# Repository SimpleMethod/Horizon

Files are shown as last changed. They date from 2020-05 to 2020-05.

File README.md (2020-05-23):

# 📡Horizon - Meteorological System based on Internet of things

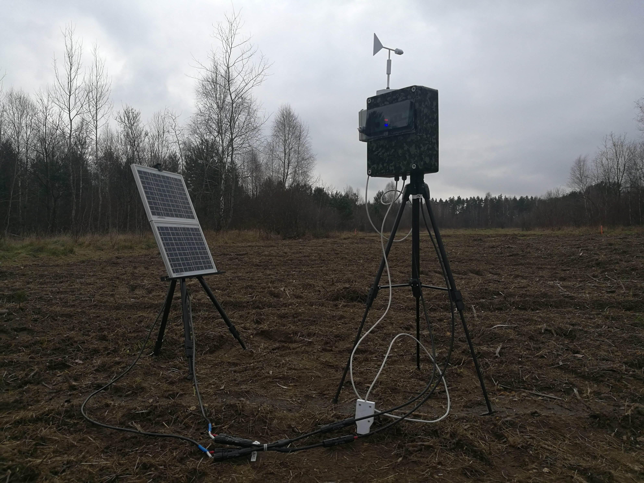
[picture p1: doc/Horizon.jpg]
Horizon in action


# 🥰 Best engineering thesis at university of technology in faculty of Electrical Engineering, Automatics and Computer Science 🥰
https://weaii.tu.kielce.pl/2020/05/15/wyniki-konkursu-prac-dyplomowych-ieee-2020/

# 🧗‍♂️Main milestones

1. Development of a device for measuring atmospheric conditions.
2. Development of a device for receiving telemetry and sending it to IoT server. 
3. Development of an IoT server able to collect data and analyse.
4. Development of an instrument for wind direction mapping.  

# 🚀 Features
 1. Getting meteorological data such as:
 - Air temperature,
 - Atmospheric pressure,
- Air humidity,
- Soil moisture,
- Wind direction,
- Dust value 2.5 PM and 10 PM.
2.  Communication between weather stations and base stations using IEEE 802.11 standard.
3.  Sending received data to IoT server via GSM communication from base stations.
4.  Ability to view data via a graphical interface from any device.
5. IoT server aggregating and analyzing data. 

# 🗺️ Technologies used in project 
1. Weather station:
- Based on two microcontainers:  STM32 and ESP32 programmed in C++. Development of necessary libraries based on technical documentation,
- Used LTC415 as voltage monitor,
- Photovoltaic panels,
- Voltage regulator,
- Gel rechargeable battery.
2. Receiving station:
- Used ESP32  programmed in C++. Development of necessary libraries based on technical documentation,
- Used SIM700e as GSM modem.
3. IoT server:
- Used microservice architecture,
- Based completely on AWS services (AWS Lambda, Amazon DynamoDB, API gateway, IAM), Lambda programmed in Node.JS,
- Graphical interface based on AngularJS running in one page. 

# 🧪 Visualization of weather station PCB 
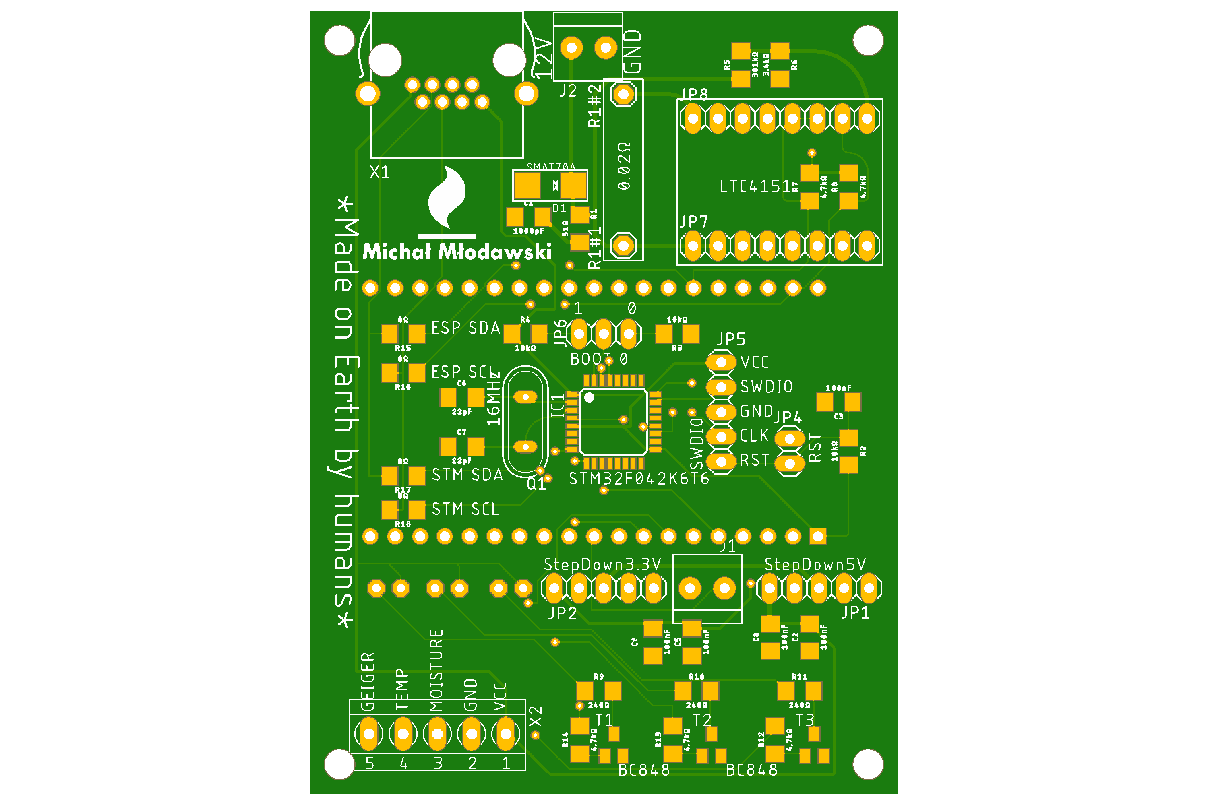
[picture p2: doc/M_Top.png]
Visualization of weather station PCB

## 🧶  Weather station communication diagram
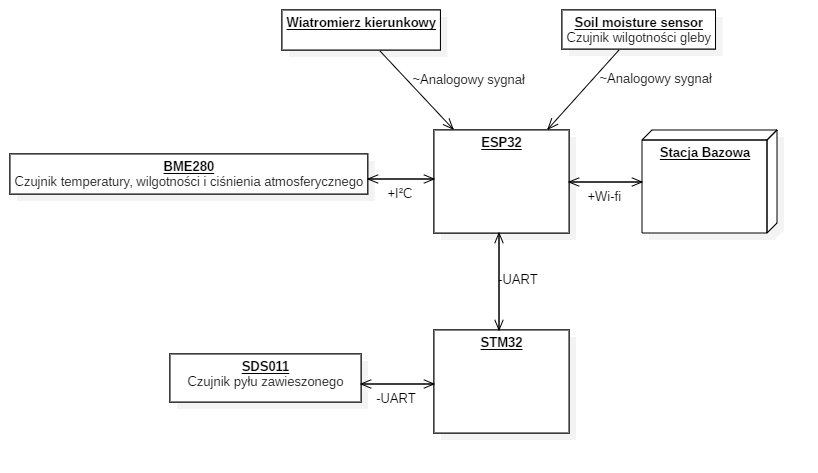
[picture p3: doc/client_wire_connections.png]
Weather station communication diagram


# 📈  Communication diagram
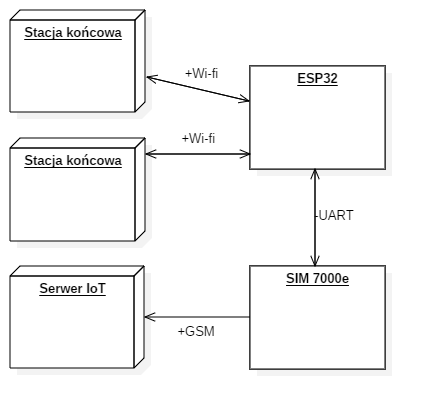
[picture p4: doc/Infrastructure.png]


# 🧊 Database schema
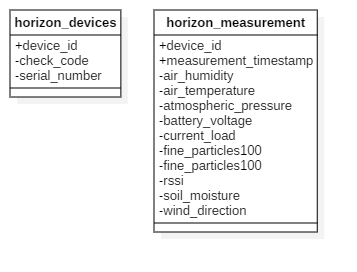
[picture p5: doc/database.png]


# 📙 Soil moisture sensor case
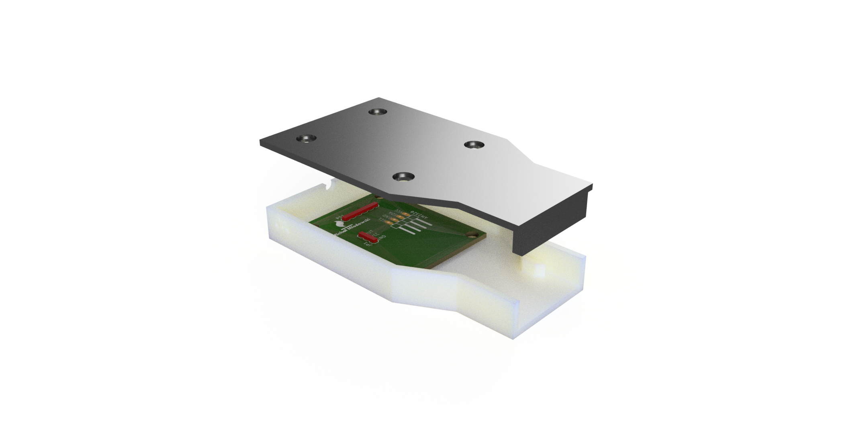
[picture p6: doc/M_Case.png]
Soil moisture sensor case


# 🧭 Wind vane 
Working on the measurement of change of resistance.
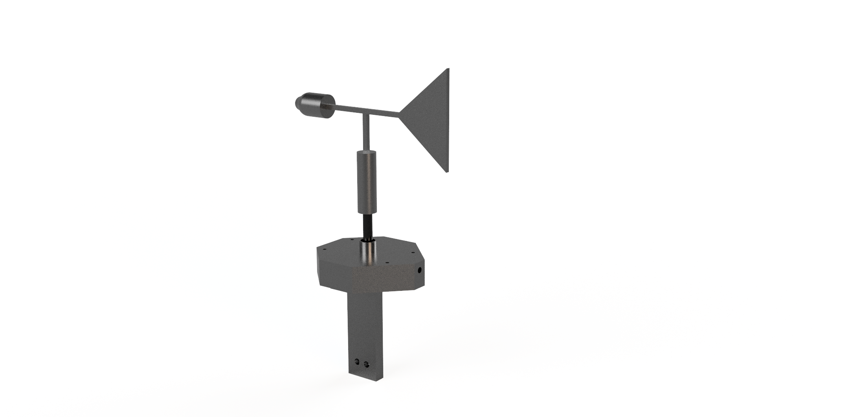
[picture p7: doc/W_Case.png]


## Visualization of PCB
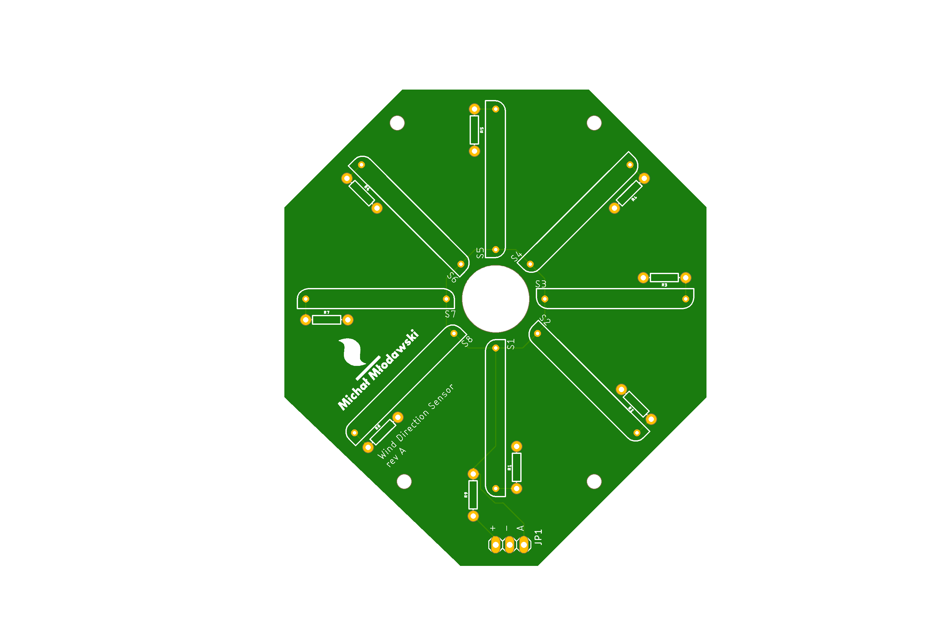
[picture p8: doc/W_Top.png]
Wind vane pcb


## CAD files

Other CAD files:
Client station/Wiring diagram of entire system/Wiring diagram AutoCAD Electrical/Stacja końcowa.dwg

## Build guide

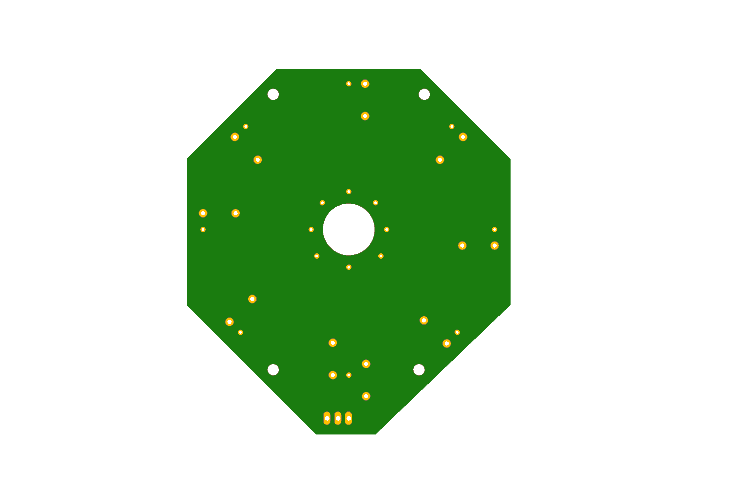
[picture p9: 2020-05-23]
Client station/Weather vane/PCB files/Wiring diagram PNG files/Graphical visualisation of PCB/Botton side.png

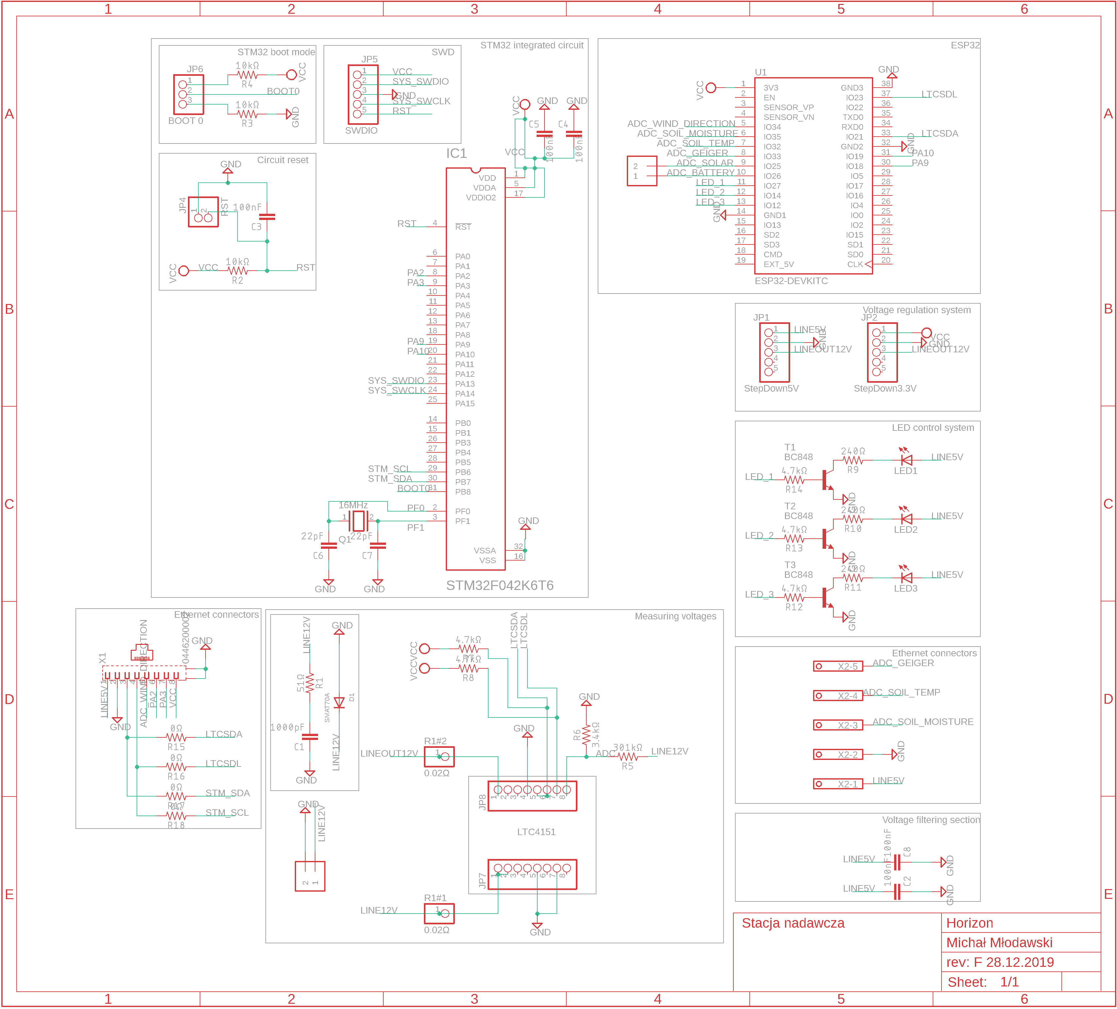
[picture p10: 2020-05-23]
Client station/Mainboard pcb files/Wiring diagram PNG files/Wiring diagram.png

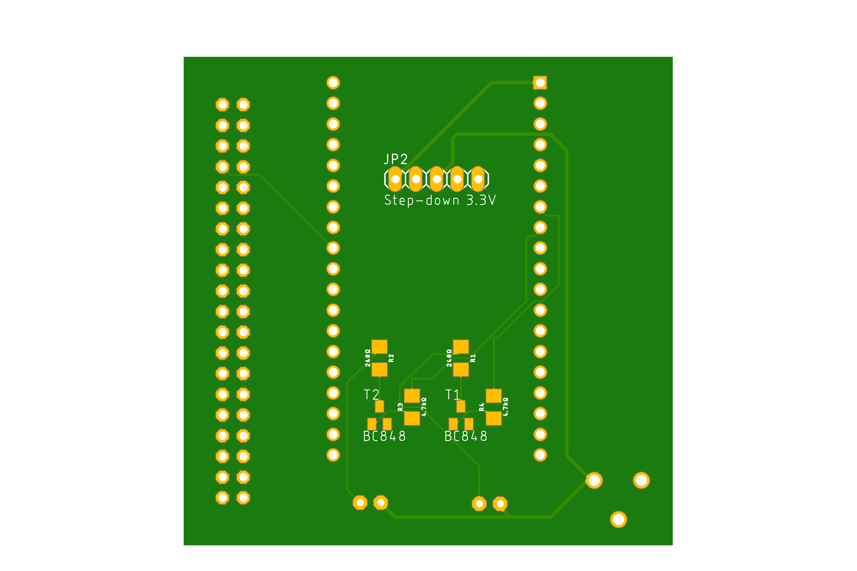
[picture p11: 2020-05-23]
Base station/Mainboard pcb files/Wiring diagram PNG files/Graphical visualisation of PCB/Botton side.png

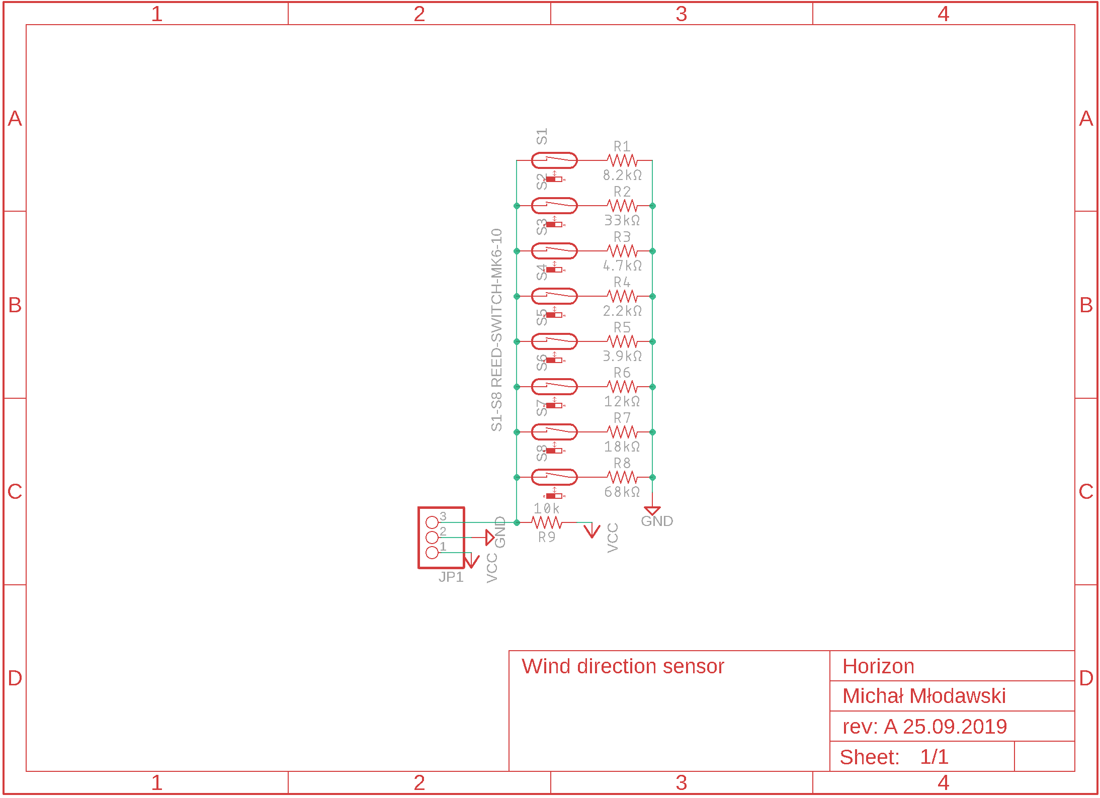
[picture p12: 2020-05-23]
Client station/Weather vane/PCB files/Wiring diagram PNG files/Wiring diagram/Wind direction sensor.png

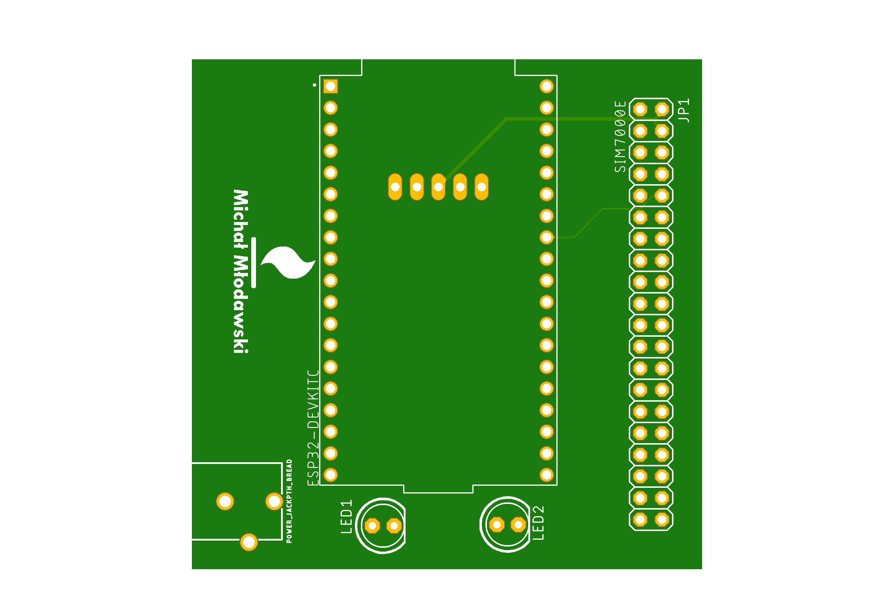
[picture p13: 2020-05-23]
Base station/Mainboard pcb files/Wiring diagram PNG files/Graphical visualisation of PCB/TOP SIDE.png

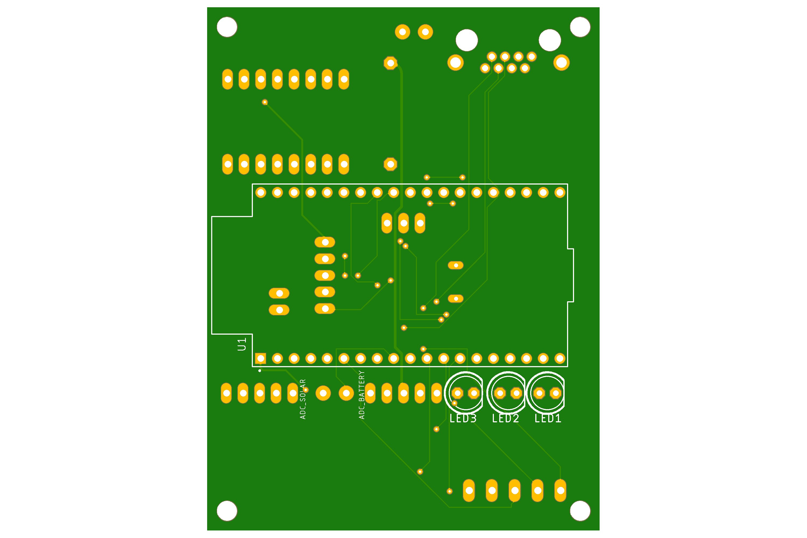
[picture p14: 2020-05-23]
Client station/Mainboard pcb files/Wiring diagram PNG files/BOTTON.png

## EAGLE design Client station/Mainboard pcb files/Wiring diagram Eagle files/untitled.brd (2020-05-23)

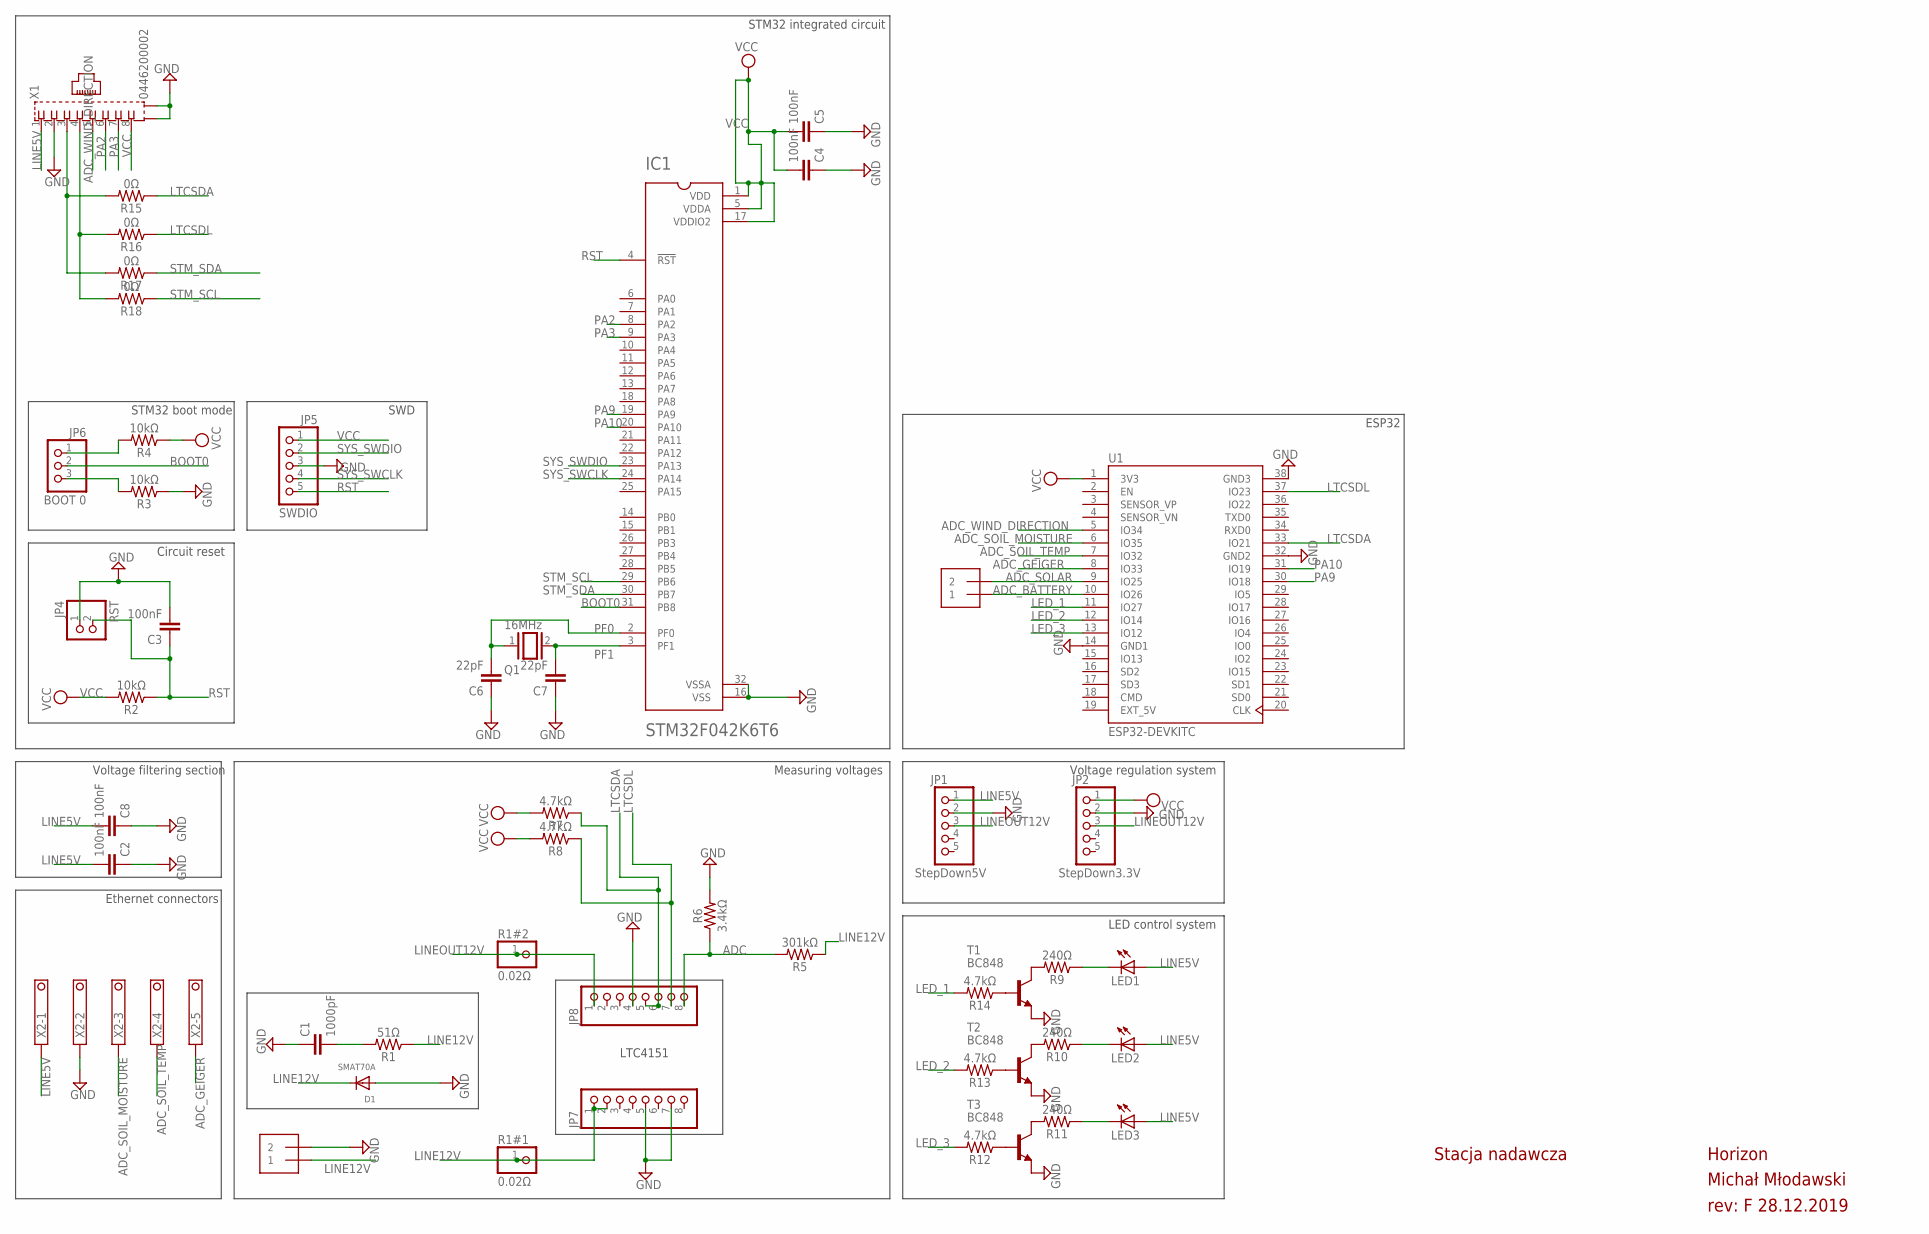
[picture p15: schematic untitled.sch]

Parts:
C1: 1000pF; 1206
C2, C3, C4, C5, C8: 100nF; 1206
C6, C7: 22pF; 1206
D1: SMAT70A; SMADIODE
IC1: STM32F042K6T6; QFP80P900X900X160-32N
J1, J2: 1X2-3.5MM
JP1: StepDown5V; 1X05
JP2: StepDown3.3V; 1X05
JP4: RST; 1X02
JP5: SWDIO; 1X05
JP6: BOOT 0; 1X03
JP7, JP8: PINHD-1X8; 1X08
LED1, LED2, LED3: LED5MM
Q1: 16MHz; QS
R1: 51Ω; 1206
R1#1, R1#2: 0.02Ω; 1X01
R2, R3, R4: 10kΩ; 1206
R5: 301kΩ; 1206
R6: 3.4kΩ; 1206
R7, R8, R12, R13, R14: 4.7kΩ; 1206
R9, R10, R11: 240Ω; 1206
R15, R16, R17, R18: 0Ω; 1206
T1, T2, T3: BC848; SOT23
U1: ESP32-DEVKITC; MODULE_ESP32-DEVKITC
X1: 0446200002
X2: TERMINAL-BLOCK-3.5MM-5-PIN-LONG-PAD; TERMINAL-BLOCK-5-PIN-3.5MM-LONG-PAD

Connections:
ADC: JP8.8, R5.2, R6.1
ADC_BATTERY: J1.1, U1.10 (IO26)
ADC_GEIGER: U1.8 (IO33), X2.5
ADC_SOIL_MOISTURE: U1.6 (IO35), X2.3
ADC_SOIL_TEMP: U1.7 (IO32), X2.4
ADC_SOLAR: J1.2, U1.9 (IO25)
ADC_WIND_DIRECTION: U1.5 (IO34), X1.5
BOOT0: IC1.31 (PB8), JP6.2
EXT_5V: U1.19 (EXT_5V)
GND: C1.1, C2.1, C3.2, C4.1, C5.1, C6.1, C7.1, C8.1, D1.A, IC1.16 (VSS), IC1.32 (VSSA), J2.2, JP1.2, JP2.2, JP4.1, JP5.3, JP7.5, JP7.7, JP8.4, R3.1, R6.2, T1.2 (E), T2.2 (E), T3.2 (E), U1.14 (GND1), U1.32 (GND2), U1.38 (GND3), X1.2, X1.S@1 (S1), X1.S@2 (S2), X2.2
LED_1: R14.2, U1.11 (IO27)
LED_2: R13.2, U1.12 (IO14)
LED_3: R12.2, U1.13 (IO12)
LINE5V: C2.2, C8.2, JP1.1, LED1.A, LED2.A, LED3.A, X1.1, X2.1
LINE12V: D1.C, J2.1, JP7.1, JP7.2, R1.1, R1#1.1, R5.1
LINEOUT12V: JP1.3, JP2.3, JP8.1, R1#2.1
LTCSDA: JP8.5, JP8.6, R7.1, R15.1, U1.33 (IO21)
LTCSDL: JP8.7, R8.1, R16.1, U1.37 (IO23)
unnamed: R9.2, T1.3 (C)
unnamed: R10.2, T2.3 (C)
unnamed: JP6.1, R4.2
unnamed: JP6.3, R3.2
unnamed: R11.2, T3.3 (C)
unnamed: C1.2, R1.2
unnamed: R12.1, T3.1 (B)
unnamed: R13.1, T2.1 (B)
unnamed: R14.1, T1.1 (B)
unnamed: LED3.K (C), R11.1
unnamed: LED2.K (C), R10.1
unnamed: LED1.K (C), R9.1
unnamed: R16.2, R18.2, X1.4
unnamed: R15.2, R17.2, X1.3
PA2: IC1.8 (PA2), X1.6
PA3: IC1.9 (PA3), X1.7
PA9: IC1.19 (PA9), U1.30 (IO18)
PA10: IC1.20 (PA10), U1.31 (IO19)
PF0: C6.2, IC1.2 (PF0), Q1.1
PF1: C7.2, IC1.3 (PF1), Q1.2
RST: C3.1, IC1.4 (!RST), JP4.2, JP5.5, R2.1
STM_SCL: IC1.29 (PB6), R18.1
STM_SDA: IC1.30 (PB7), R17.1
SYS_SWCLK: IC1.24 (PA14), JP5.4
SYS_SWDIO: IC1.23 (PA13), JP5.2
VCC: C4.2, C5.2, IC1.1 (VDD), IC1.5 (VDDA), IC1.17 (VDDIO2), JP2.1, JP5.1, R2.2, R4.1, R7.2, R8.2, U1.1 (3V3), X1.8

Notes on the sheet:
Circuit reset
SWD
Voltage regulation system
Ethernet connectors
STM32 boot mode
STM32 integrated circuit
Voltage filtering section
ESP32
LED control system
LTC4151
Measuring voltages
rev: F 28.12.2019
Michał Młodawski
Horizon
Stacja nadawcza

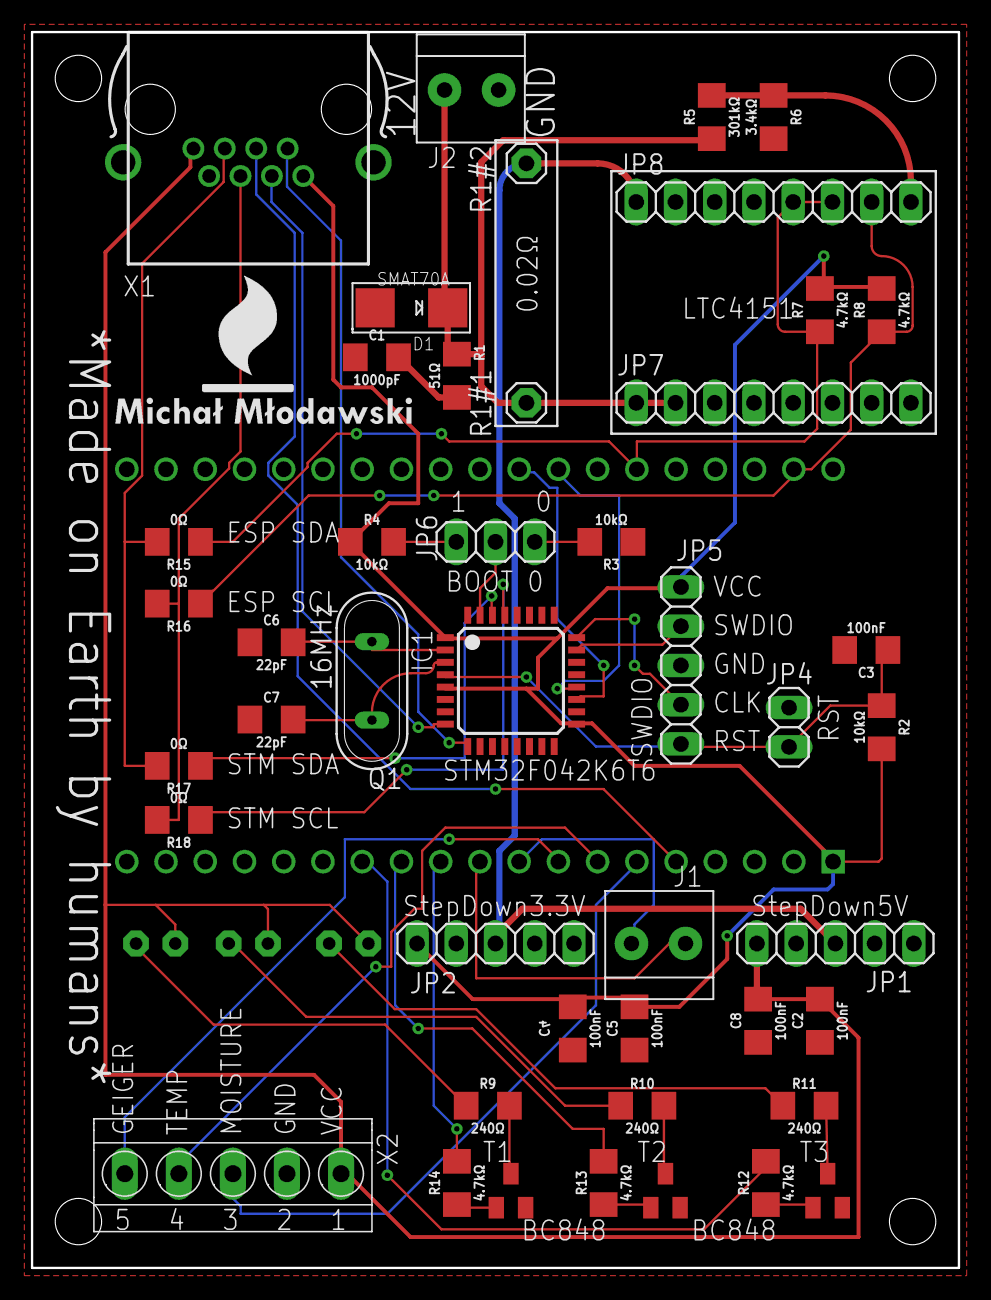
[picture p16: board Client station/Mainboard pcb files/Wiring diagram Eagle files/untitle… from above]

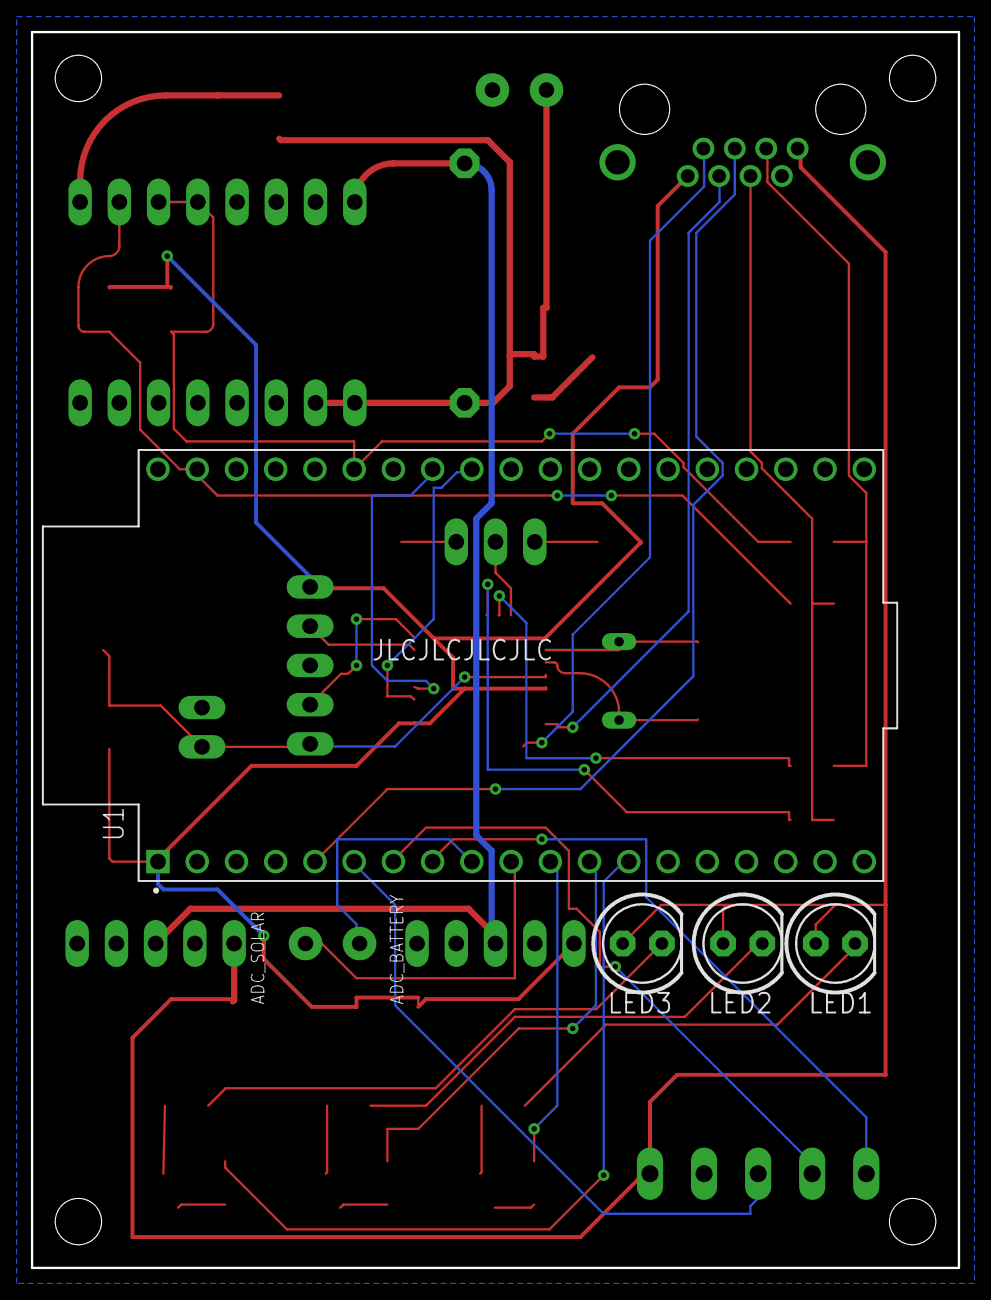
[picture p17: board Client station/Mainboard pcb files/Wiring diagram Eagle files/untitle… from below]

Board: 2 copper layers, 60.0 x 80.0 mm, 49 parts (4 on the bottom side), 43 nets.

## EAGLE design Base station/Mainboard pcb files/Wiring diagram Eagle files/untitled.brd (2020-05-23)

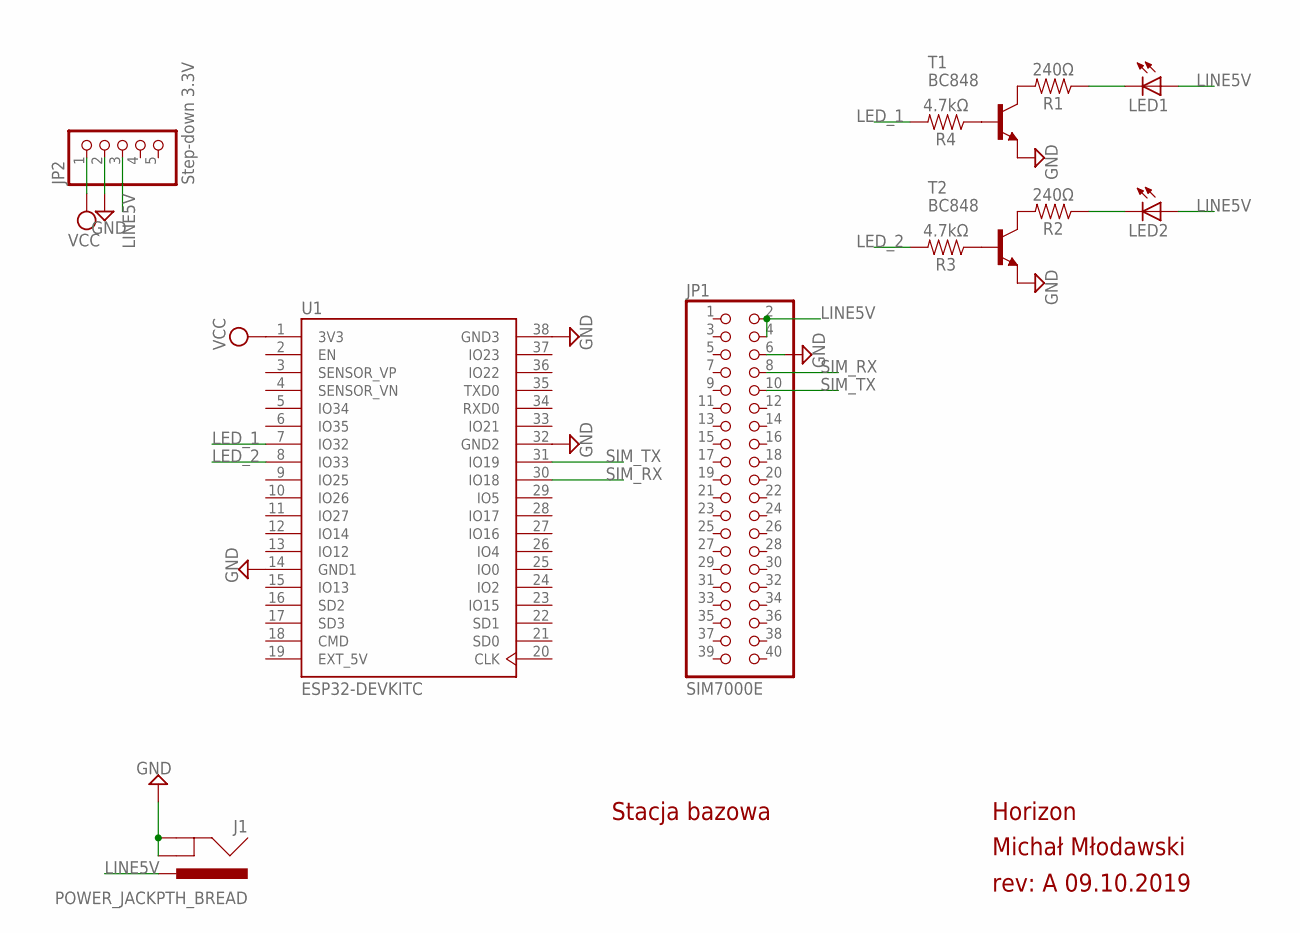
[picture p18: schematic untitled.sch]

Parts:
J1: POWER_JACKPTH_BREAD; POWER_JACK_PTH_BREAD
JP1: SIM7000E; 2X20
JP2: Step-down 3.3V; 1X05
LED1, LED2: LED5MM
R1, R2: 240Ω; 1206
R3, R4: 4.7kΩ; 1206
T1, T2: BC848; SOT23
U1: ESP32-DEVKITC; MODULE_ESP32-DEVKITC

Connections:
EXT_5V: U1.19 (EXT_5V)
GND: J1.GND, J1.GNDBREAK, JP1.6, JP2.2, T1.2 (E), T2.2 (E), U1.14 (GND1), U1.32 (GND2), U1.38 (GND3)
LED_1: R4.2, U1.7 (IO32)
LED_2: R3.2, U1.8 (IO33)
LINE5V: J1.PWR, JP1.2, JP1.4, JP2.3, LED1.A, LED2.A
unnamed: R1.2, T1.3 (C)
unnamed: R2.2, T2.3 (C)
unnamed: R3.1, T2.1 (B)
unnamed: R4.1, T1.1 (B)
unnamed: LED2.K (C), R2.1
unnamed: LED1.K (C), R1.1
SIM_RX: JP1.8, U1.30 (IO18)
SIM_TX: JP1.10, U1.31 (IO19)
VCC: JP2.1, U1.1 (3V3)

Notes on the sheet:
rev: A 09.10.2019
Michał Młodawski
Horizon
Stacja bazowa

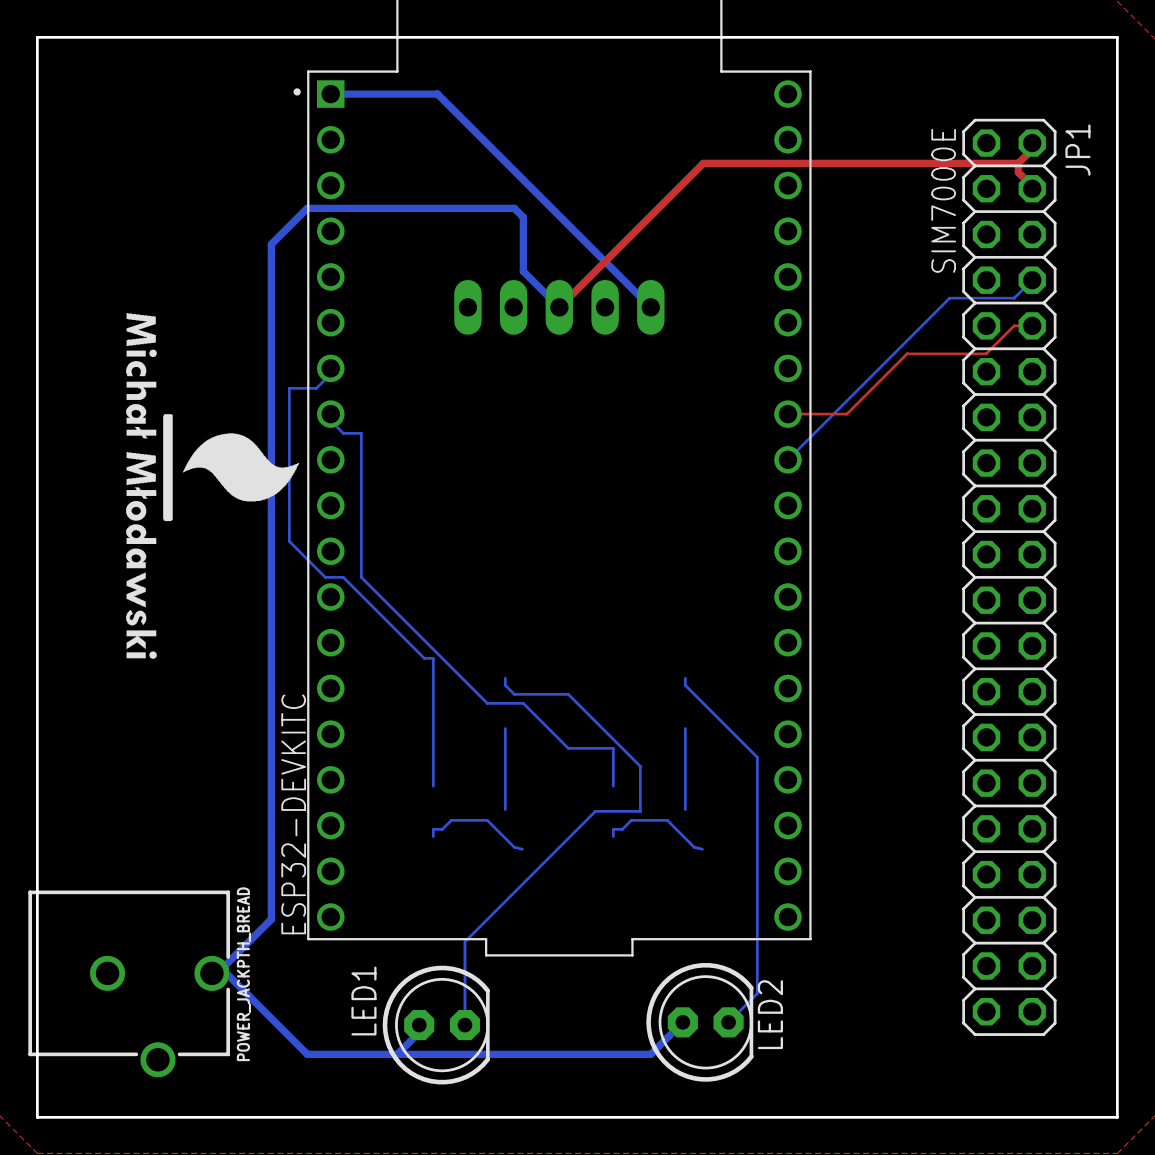
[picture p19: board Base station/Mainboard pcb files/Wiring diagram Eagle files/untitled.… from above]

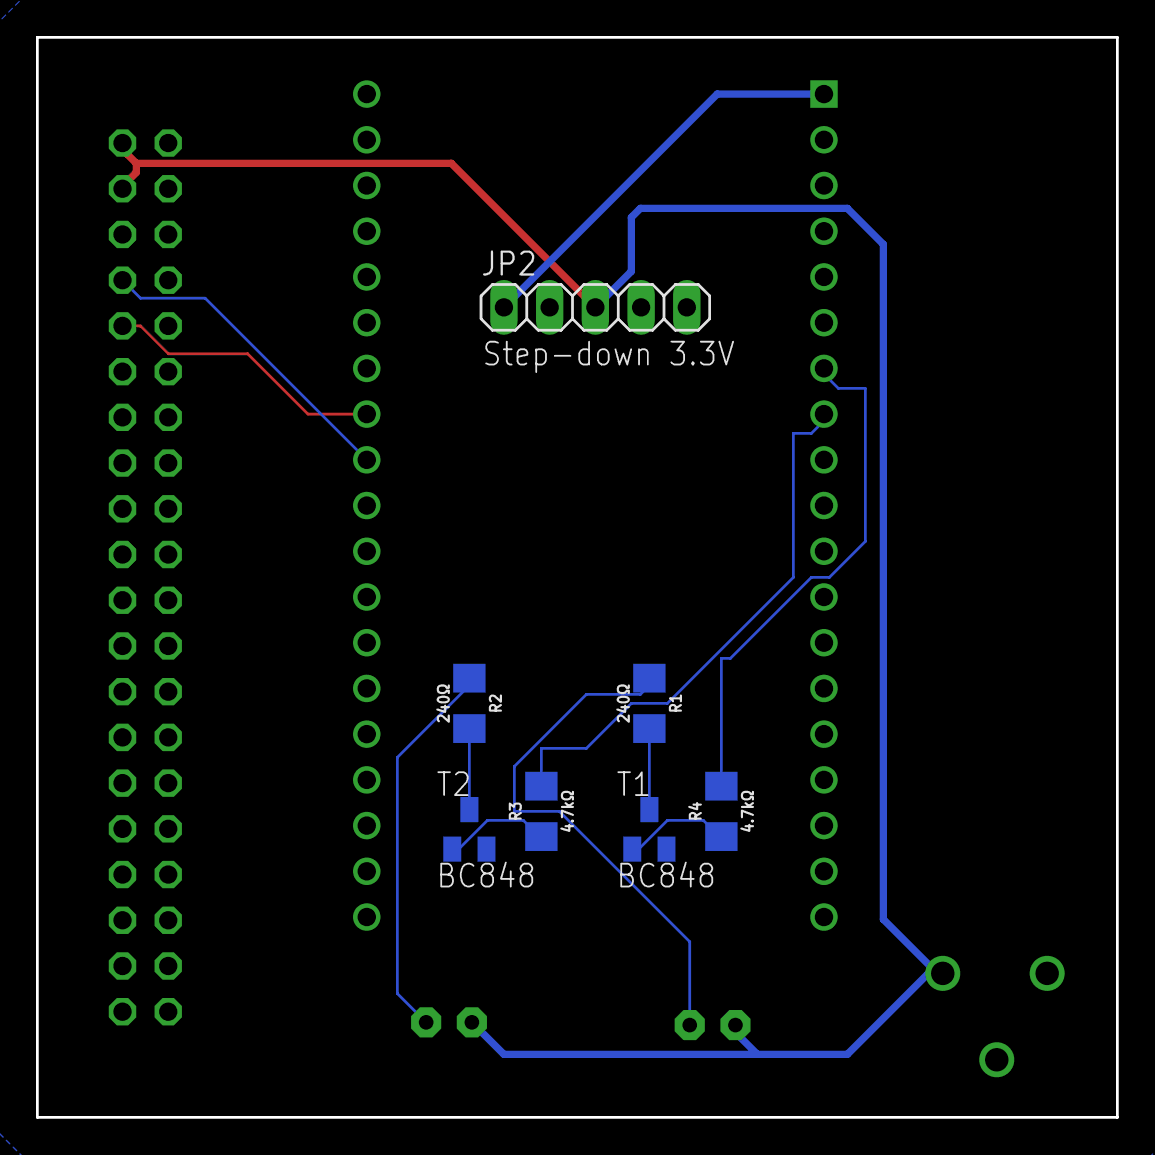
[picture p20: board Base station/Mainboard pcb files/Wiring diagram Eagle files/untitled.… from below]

Board: 2 copper layers, 60.0 x 60.0 mm, 12 parts (7 on the bottom side), 13 nets.

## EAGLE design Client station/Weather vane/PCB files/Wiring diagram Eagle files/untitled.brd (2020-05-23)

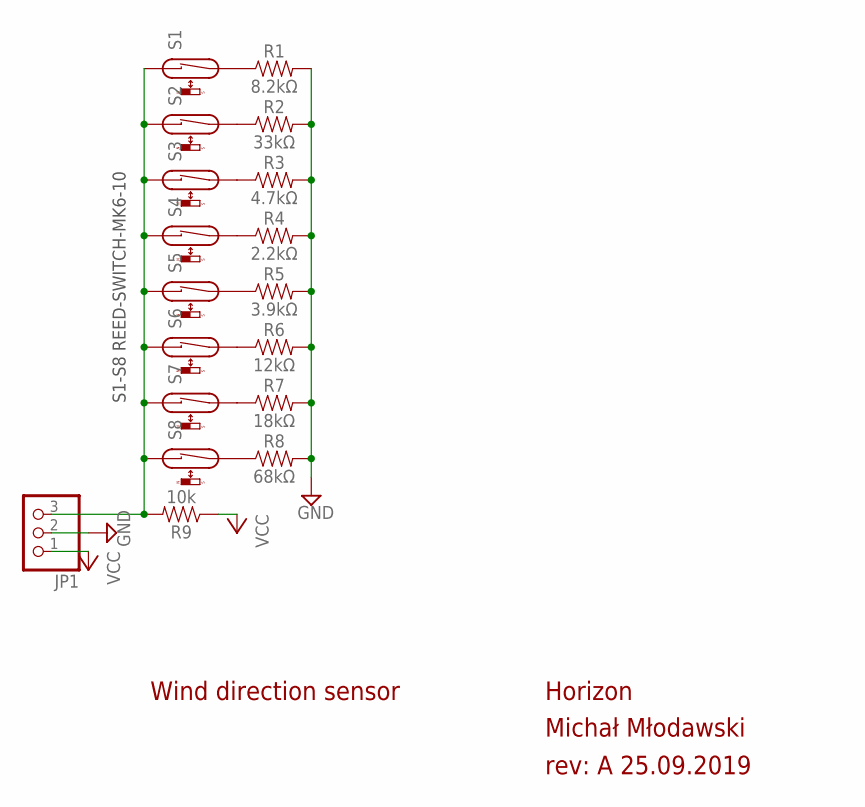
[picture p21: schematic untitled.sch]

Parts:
JP1: PINHD-1X3; 1X03
R1: 8.2kΩ; AXIAL-0.3
R2: 33kΩ; AXIAL-0.3
R3: 4.7kΩ; AXIAL-0.3
R4: 2.2kΩ; AXIAL-0.3
R5: 3.9kΩ; AXIAL-0.3
R6: 12kΩ; AXIAL-0.3
R7: 18kΩ; AXIAL-0.3
R8: 68kΩ; AXIAL-0.3
R9: 10k; AXIAL-0.3
S1, S2, S3, S4, S5, S6, S7, S8: REED-SWITCH-MK6-10; MK6-10

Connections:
GND: JP1.2, R1.P$2 (2), R2.P$2 (2), R3.P$2 (2), R4.P$2 (2), R5.P$2 (2), R6.P$2 (2), R7.P$2 (2), R8.P$2 (2)
unnamed: R1.P$1 (1), S1.2
unnamed: R2.P$1 (1), S2.2
unnamed: R3.P$1 (1), S3.2
unnamed: R4.P$1 (1), S4.2
unnamed: R5.P$1 (1), S5.2
unnamed: R6.P$1 (1), S6.2
unnamed: R7.P$1 (1), S7.2
unnamed: R8.P$1 (1), S8.2
unnamed: JP1.3, R9.P$2 (2), S1.1, S2.1, S3.1, S4.1, S5.1, S6.1, S7.1, S8.1
VCC: JP1.1, R9.P$1 (1)

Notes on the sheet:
S1-S8 REED-SWITCH-MK6-10
rev: A 25.09.2019
Michał Młodawski
Horizon
Wind direction sensor

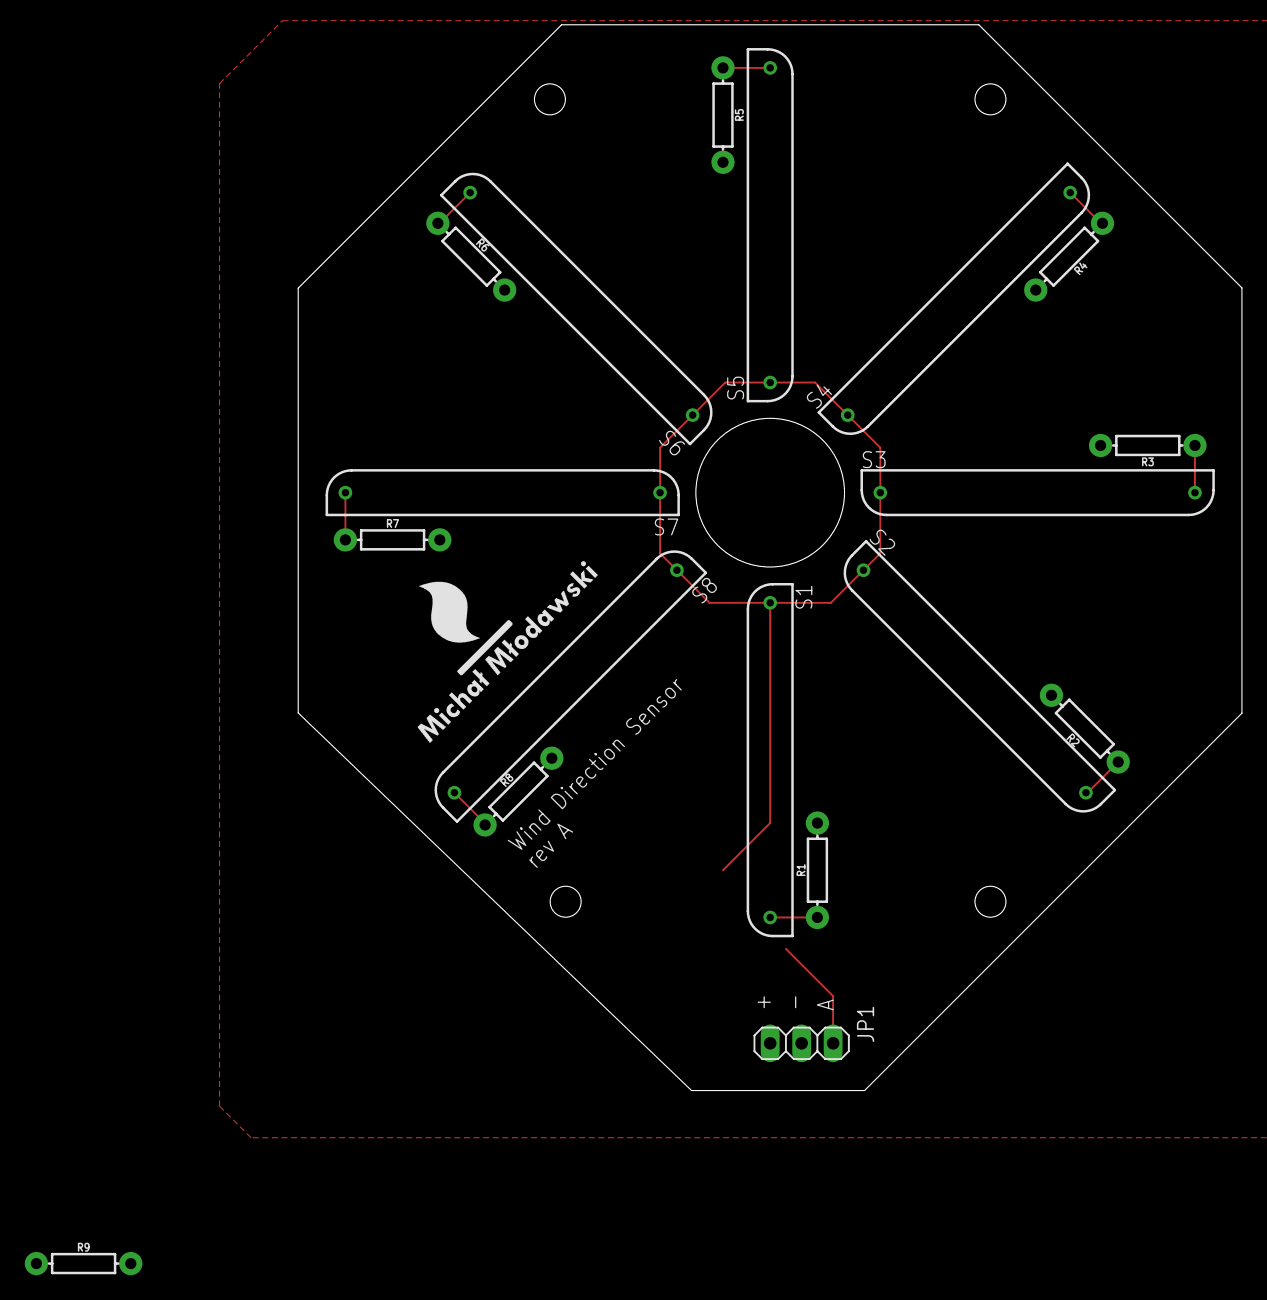
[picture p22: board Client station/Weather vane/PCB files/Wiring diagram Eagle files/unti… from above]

Board: 2 copper layers, 76.2 x 86.0 mm, 18 parts (0 on the bottom side), 11 nets.

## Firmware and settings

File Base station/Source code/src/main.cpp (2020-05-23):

/*
 * Copyright  Michał Młodawski (SimpleMethod)(c) 2019.
 */
#include <esp_wifi.h>
#include "ESPAsyncWebServer.h"
#include <string>
#include <iostream>
#include <regex>
#include "ArduinoJson.h"
#include <FS.h>
#include "SPIFFS.h"
#include "sim.hpp"
#include "ap.hpp"
#include "SPIFFShandle.hpp"
#include "WiFihandle.hpp"
#include <ESPmDNS.h>

#include "soc/timer_group_struct.h"
#include "soc/timer_group_reg.h"


using namespace std;

#define FORMAT_SPIFFS_IF_FAILED true
#define NORMAL_MODE true
#define ENABLE_MDNS true

#if NORMAL_MODE
IPAddress ap_local_IP(192, 168, 1, 1);
IPAddress ap_gateway(192, 168, 1, 254);
IPAddress ap_subnet(255, 255, 255, 0);
const static wifi_country_t wifi_country = {.cc = "PL",
                                            .schan = 1,
                                            .nchan = 13,
                                            .max_tx_power = 126,
                                            .policy = WIFI_COUNTRY_POLICY_AUTO};
#endif

AsyncWebServer server(80);
spiffsfs_handle sph;
wifi_handle wifihandle(sph);
AccessPoint ap;
Sim sim;
unsigned long startTime = 0;
unsigned long previousTimeUpdate = 0;
unsigned long previousTimeStationList = 0;
uint8_t semaphore = 0;

boolean connectToNetwork(const char *hostname);

void setup() {
//disableCore0WDT();
//disableCore1WDT();
//disableLoopWDT();
pinMode(32, OUTPUT);
pinMode(33, OUTPUT);

  if (!SPIFFS.begin(FORMAT_SPIFFS_IF_FAILED)) {
    Serial.println("An Error has occurred while mounting SPIFFS");
    return;
  }

  if (!sph.checkFile("/wifi.bin")) {
    sph.writeFile("/wifi.bin",
                  "{ \"ssid\":\"horzion\", \"password\": \"horizon2137\"}");
  }

  wifihandle.loadConfiguration();
  digitalWrite(32,1);

  delay(1000);
digitalWrite(32,0);
  connectToNetwork("gatewayhorizon");

  Serial2.begin(115200, SERIAL_8N1, 19, 18);
  Serial.begin(115200);
  Serial.println(F("Configuring access point..."));

  server.on("/upload/data", HTTP_POST, [](AsyncWebServerRequest *request) {}, NULL,
            [](AsyncWebServerRequest *request, uint8_t *data, size_t len,
               size_t index, size_t total) mutable {
              digitalWrite(33, HIGH);
              string _BigData = string(data, data + len);
              sim.sim7000eLaunch();
              Serial.printf("[REQUEST]\t%s\r\n", _BigData.c_str());
              sim.sendpost("http://d2fw69tfosfc4v.cloudfront.net/measurement",
                           _BigData.c_str());
              _BigData = "";
              digitalWrite(33, LOW);
              request->send(200);
            });

  server.on("/connection", HTTP_GET, [](AsyncWebServerRequest *request) {
    request->send(SPIFFS, "/wifi.bin");
  });


 server.on("/", HTTP_GET, [](AsyncWebServerRequest *request) {request->send(SPIFFS, "/index.html");});
 server.on("/connection", HTTP_GET, [](AsyncWebServerRequest *request) {request->send(SPIFFS, "/wifi.bin");});
 server.on("/fonts/icomoon.eot", HTTP_GET, [](AsyncWebServerRequest *request) {request->send(SPIFFS, "/fonts/icomoon.eot");});
 server.on("/fonts/icomoon.svg", HTTP_GET, [](AsyncWebServerRequest *request) {request->send(SPIFFS, "/fonts/icomoon.svg");});
 server.on("/fonts/icomoon.ttf", HTTP_GET, [](AsyncWebServerRequest *request) {request->send(SPIFFS, "/fonts/icomoon.ttf");});
 server.on("/fonts/icomoon.woff", HTTP_GET, [](AsyncWebServerRequest *request) {request->send(SPIFFS, "/fonts/icomoon.woff");});
 server.on("/angular.min.js", HTTP_GET, [](AsyncWebServerRequest *request) {request->send(SPIFFS, "/angular.min.js");});
 server.on("/angular-route.js", HTTP_GET, [](AsyncWebServerRequest *request) {request->send(SPIFFS, "/angular-route.js");});
 server.on("/app.js", HTTP_GET, [](AsyncWebServerRequest *request) {request->send(SPIFFS, "/app.js");});
 server.on("/aws.png", HTTP_GET, [](AsyncWebServerRequest *request) {request->send(SPIFFS, "/aws.png");});
 server.on("/bootstrap.min.css", HTTP_GET, [](AsyncWebServerRequest *request) {request->send(SPIFFS, "/bootstrap.min.css");});
 server.on("/home.html", HTTP_GET, [](AsyncWebServerRequest *request) {request->send(SPIFFS, "/home.html");});
 server.on("/index.html", HTTP_GET, [](AsyncWebServerRequest *request) {request->send(SPIFFS, "/index.html");});
 server.on("/jquery.easing.js", HTTP_GET, [](AsyncWebServerRequest *request) {request->send(SPIFFS, "/jquery.easing.js");});
 server.on("/jquery.min.js", HTTP_GET, [](AsyncWebServerRequest *request) {request->send(SPIFFS, "/jquery.min.js");});
 server.on("/settings.html", HTTP_GET, [](AsyncWebServerRequest *request) {request->send(SPIFFS, "/settings.html");});
 server.on("/style.css", HTTP_GET, [](AsyncWebServerRequest *request) {request->send(SPIFFS, "/style.css");});
 server.on("/theme.js", HTTP_GET, [](AsyncWebServerRequest *request) {request->send(SPIFFS, "/theme.js");});




  server.on("/connection", HTTP_POST, [](AsyncWebServerRequest *request) {
    const char *ssid = 0;
    const char *password = 0;
    int temp = 0;
    if (request->hasParam("ssid")) {
      AsyncWebParameter *p = request->getParam("ssid");
      ssid = p->value().c_str();
      temp++;
      if (p->value().isEmpty()) {
        request->send(404, "text/html", "error");
      }
    }
    if (request->hasParam("password")) {
      AsyncWebParameter *p = request->getParam("password");
      password = p->value().c_str();
      temp++;
      if (p->value().isEmpty()) {
        request->send(404, "text/html", "error");
      }
    }
    if (temp >= 1) {
      wifihandle.saveConfiguration(ssid, password);
      request->send(200, "text/html", "ok");
    } else {
      request->send(500, "text/html", "error");
    }
  });

  server.on("/gsm/restart", HTTP_GET, [](AsyncWebServerRequest *request) {
    if (sim.sim7000eLaunch() == true) {
      request->send(200, "text/html", "ok");
    } else {
      request->send(500, "text/html", "error");
    }
  });

  server.on("/devices/list", HTTP_GET, [](AsyncWebServerRequest *request) {
#if NORMAL_MODE
    ap.getConnectedList();
    request->send(200, "text/html", ap.prettyConnectedList);
#else
     string str = R"(["192.168.1.1","127.0.0.0"]])";
    request->send(200, "text/html", ap.prettyConnectedList);
#endif

  });

  server.on("/gsm/info", HTTP_GET, [](AsyncWebServerRequest *request) {
    StaticJsonDocument<512> doc;
    string _temp;
    String temp;
    char json_string[512];

    _temp = sim.getLocalNetwork();
    temp = _temp.c_str();
    if (_temp == "Not found") {
      doc["local_network"] = F("0");
    } else {
      doc["local_network"] = temp;
    }
    _temp = sim.getSignalStrenght();
    temp = _temp.c_str();
    if (_temp == "Not found") {
      doc["signal_strenght"] = F("99");
    } else {
      doc["signal_strenght"] = temp;
    }
    _temp = sim.getIPAddress();
    temp = _temp.c_str();
    if (_temp == "Not found") {
      doc["IPAddress"] = F("0");
    } else {
      doc["IPAddress"] = temp;
    }

    _temp = sim.getAttachedToNetwork();
    temp = _temp.c_str();
    if (_temp == "Not found") {
      doc["attached_to_network"] = F("0");
    } else {
      doc["attached_to_network"] = temp;
    }

    serializeJson(doc, json_string);
    request->send(200, "application/json", json_string);
    sim.sim7000Stack.clear();
  });
  server.begin();
  Serial.println(F("Server started"));
}

void loop() {
  startTime = millis();
  if (startTime - previousTimeUpdate > 60000) {
    if (semaphore == 0) {
      sim.sim7000eLaunch();
      delay(10);
      if (sim.getLocalNetwork() == "Not found") {
        Serial.println(F("Błąd inicjalizacji polaczenia"));
      } else {
        sim.sendpost("http://httpbin.org/post", "null");
        Serial.println(F("Uruchomiono modul sim7000e"));
      }
      semaphore = 1;
    }
    previousTimeUpdate = startTime;
  }

  if (startTime - previousTimeStationList > 10000) {
    
#if NORMAL_MODE
    ap.getConnectedList();
#endif
    previousTimeStationList = startTime;
  }
}

boolean connectToNetwork(const char *hostname) {
#if NORMAL_MODE
Serial.printf("Konfiguracja: \n\r SSID: %s \n\r Password: %s", wifihandle.config.ssid,wifihandle.config.password);
  WiFi.mode(WIFI_AP);
  WiFi.setHostname("masterhorizon");
  esp_wifi_set_protocol(WIFI_IF_AP, WIFI_PROTOCOL_11B | WIFI_PROTOCOL_11G | WIFI_PROTOCOL_11N);
 Serial.println(WiFi.softAPConfig(ap_local_IP, ap_gateway, ap_subnet)
                     ? "Configuring Soft AP"
                     : "Error in Configuration");
  esp_wifi_set_country(&wifi_country);
  WiFi.softAP(wifihandle.config.ssid, wifihandle.config.password);

  Serial.println(WiFi.softAPIP());
#if ENABLE_MDNS
  if (!MDNS.begin("esp32")) {
    Serial.println("Error setting up MDNS responder!");
    while (1) {
      delay(1000);
    }
  }
  Serial.println("mDNS responder started");
  MDNS.addService("http", "tcp", 80);
#endif
  return true;
#else

  WiFi.mode(WIFI_STA);
  WiFi.begin(wifihandle.config.ssid, wifihandle.config.password);
  Serial.println("");

  while (WiFi.status() != WL_CONNECTED) {
    delay(500);
    Serial.print(".");
  }

  WiFi.setHostname(hostname);

#if DEBUG_WIFI
  Serial.println("");
  Serial.print("Connected to ");
  Serial.println(WiFi.SSID());
  Serial.print("IP address: ");
  Serial.println(WiFi.localIP());
  Serial.print("RSSI: ");
  Serial.println(WiFi.RSSI());
#endif

#if ENABLE_MDNS
  if (!MDNS.begin("esp32")) {
    Serial.println("Error setting up MDNS responder!");
    while (1) {
      delay(1000);
    }
  }
  Serial.println("mDNS responder started");
  MDNS.addService("http", "tcp", 80);
#endif
  if (WiFi.status() == WL_CONNECTED) {
    return true;
  } else {
    return false;
  }
#endif
}

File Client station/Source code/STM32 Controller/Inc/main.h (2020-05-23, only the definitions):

#define ADC_SOIL_MISTURE_Pin GPIO_PIN_1
#define ADC_SOIL_MISTURE_GPIO_Port GPIOA
#define UART2_SDS011_TX_Pin GPIO_PIN_2
#define UART2_SDS011_TX_GPIO_Port GPIOA
#define UART2_SDS011_RX_Pin GPIO_PIN_3
#define UART2_SDS011_RX_GPIO_Port GPIOA
#define ADC_WIND_DIRECTION_Pin GPIO_PIN_4
#define ADC_WIND_DIRECTION_GPIO_Port GPIOA
#define UART1_ESP_TX_Pin GPIO_PIN_9
#define UART1_ESP_TX_GPIO_Port GPIOA
#define UART1_ESP_RX_Pin GPIO_PIN_10
#define UART1_ESP_RX_GPIO_Port GPIOA
#define I2CL_BME_SCL_Pin GPIO_PIN_6
#define I2CL_BME_SCL_GPIO_Port GPIOB
#define I2C1_BME_SDA_Pin GPIO_PIN_7
#define I2C1_BME_SDA_GPIO_Port GPIOB

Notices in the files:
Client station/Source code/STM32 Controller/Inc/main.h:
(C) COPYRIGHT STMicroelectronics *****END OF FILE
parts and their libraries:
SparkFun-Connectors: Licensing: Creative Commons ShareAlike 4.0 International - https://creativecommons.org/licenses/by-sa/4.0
